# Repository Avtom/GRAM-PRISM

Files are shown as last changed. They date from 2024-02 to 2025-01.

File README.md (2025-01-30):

# GRAM PRI$M

# Introduction 
The **PRI$M** is a modular take on the Prism, originally designed by WunWae. It has the standard pinout for firmwares like HayBox and Pico-Rectangle, and is also compatible with more fleshed-out FGC firmwares like GP2040-CE. The key distinctive features between the original Prism and the PRI$M is the USB-C connectivity, and the modular panels that can be replaced and swapped to change the hand layouts without purchasing a whole new controller. With industrial design from GRAM, PCB designed by Quark.Works, this guide goes over a DIY-friendly approach to building and modifying the PRI$M to suit your needs.

**If you would like to support the developers of this project, consider purchasing parts like buttons, PCBs, USB-C to GCC cables, and official GRAM builds at [GRAMCTRL.COM](https://www.gramctrl.com) rather than a fab house.**

For the Arcade version of the PRI$M, please go to [this section of the documentation](https://github.com/Avtom/GRAM-PRISM/tree/arcade-V1/Arcade%20%20v1)

IMG_8768 (1)

Included Files
-
Included in this repo is all the files needed to get started with a PRI$M build:
- **PRI$M Frame .stl files**
- **Aluminum Panel** Gerber files *(5 of 'em!)*
- **PCB Gerbers** for multiple hand layouts and a panelized version for the standard layout

Additional Information
-
If you want more info around GRAM builds, both open source and official builds, please join the [GRAM Digital Controllers Discord](https://discord.gg/6TuHw2r2X4) to ask questions and work with the community! I would love to see people creating new interesting designs, and building upon our initial framework.

Thanks & Acknowledgements
-
There are several people who made this project possible, either directly or indirectly.
- [Quark](https://twitter.com/quark_works), who did the PCB design on this and many other GRAM projects.
- [WunWae](https://twitter.com/WuhnWae), who developed the ergonomics and original Prism design. Thank you for your blessing on this crazy project!
- My life and business partner [BRUISES](https://twitter.com/bruisesxo), who has turned GRAM into what it is today, and had incredible patience with me as I toiled away at my computer late into the night designing this thing.

# Ordering & Customization Guide
While most of these files are universal and can be used at any fab house, **JLCPCB** has become the de-facto standard for DIY box manufacturing. This is due to their hyper-affordable pricing and low minimum order quantity.

Bill of Materials
-
Per GRAM PRI$M, you will need (some files can be made using this repository, but I will link to places to purchase them if you would like to avoid MOQs)
- 1 x PRI$M PCB set *(either panelized, or individual PCBs)*
- 1 x set of PRI$M Aluminum Panels
- 20 x [Kailh Choc V1 switches](https://www.moergo.com/products/kailh-choc-v1-key-switches-red-brown-white-pro-red-20-pack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) (Red, Red Pro, and Whites are all great choices)
- 20 x [PG1350 Hotswap Sockets](https://mkultra.click/kailh-hotswap-sockets)
- 20 x Choc v1 keycaps *(I recommend MBK profile)*
- 1 x GRAM PRI$M Frame
- 8 x [M5x0.8 8mm Low-Profile Socket Head Screws](https://www.mcmaster.com/92855A507)
- 2 x [M2.5x0.45 4mm Button Head Screws](https://www.mcmaster.com/catalog/130/3434/97763A412)
- 1 x [4" JST 6-pin Socket to Socket Reversed cable assembly](https://www.digikey.com/en/products/detail/jst-sales-america-inc/A06SR06SR30K102A/9922193)
- 1 x [4" 14-pin FPC Cable](https://www.digikey.com/en/products/detail/molex/0152670295/4427171)

*Optional*
- USB-C to GCC cable for console/adapter play

Tools Needed
-
This guide assumes a level of knowledge on soldering and computer literacy. General tool requirements are:
- Soldering iron
- Solder
- USB-C to USB-A cable
- 3mm hex key/allen wrench
- Pliers
- Patience :)

The PCB
-
***Note: Since the ordering process of the PRI$M is almost identical to the [SLIM](https://github.com/GrammyMoney/GRAM-SLIM), I have used the ordering guide from the SLIM here. You may need to do more repetitions of these steps depending on which PCB you are printing, and you need to do the panel steps for all 5 aluminum panels.***

The PCB Fabrication files should come in the form of a *Gerber ZIP file* and *bom/cpl files* (usually in Excel spreadsheet formats).

Drag them into the "Upload Gerbers" box at JLCPCB and this page will pop up:



Here you can change the color of the PCB. Green is the fastest and cheapest from JLC, but their black PCBs look *siiiiiick*. The only setting I recommend you change is to check "**Yes**" on *Confirm Production file*. This allows for any mistakes to be ironed out by their engineers.

Towards the bottom of the page, you want to turn on the switch for **PCB ASSEMBLY**.



Make sure you are assembling the *Bottom Side* of the PCB, and make sure to set *Confirm Parts Placement* to "**Yes**". None of the advanced options need to be changed.

Upon confirming your PCB Assembly options, you'll be taken to the Assembly wizard. Clicking next will give you a location to upload the *BOM* and *CPL* files (*CPL* is referred to as *Positions* in the GRAM Slim files). Once you click through, you'll be brought to you BOM list.



This will allow you to modify parts if there's any low stock. There's a line at the bottom for CH1-CH21 with some red text. This is for assembling hotswap sockets, which is not recommended for JLC, as you have to preorder them. when you click **next**, continue by clicking *Do not place*.



The wizard looks intimidating, but good news! Since you're confirming part placement, the JLC engineers will fix any errors. Just go ahead and continue.

There you have it! Your PCB is ready to order. As of the time of this writing, a set of 5 assembled boards costs $56.07 before shipping.

The Panels
-
The process of ordering aluminum panels from JLC is similar to the PCB ordering process, but much simpler. Start by dragging the **GRAM Slim Top** Zip file into the JLC upload window. We want an aluminum PCB, 1.6mm. You can choose either white or black coating (white tends to be glossy, black is matte but a fingerprint magnet). 



Under High-spec Options, make sure to remove order number, or else they'll put an ugly serial number on the panel.

Once you save to cart, you'll see this screen:



Here you can add the **GRAM Slim Bottom** Zip file, and it will copy all your settings from the Top panel. Save to cart, and you're ready to check out with your PCBs!

*Note: JLCPCB cannot transact PCB and 3D printing orders together, so place this order, then move on to 3D printing.*

The Frame
-
The frame file is pretty self explanatory. Just go into JLC's 3D printing section, drop the STL file in, and choose your material. I recommend black Resin, but LEDO 6060 is a great, low cost alternative. The only material I recommend against is the textured Nylon options, as the tolerances between the frame and panels are extremely tight, and the texture could interfere with that. make sure the surface finish is set to *sanded*. 

The website will flag some possible errors (Inverted normals, Multi-shells, Possible noise shells) but if you have not modified the .stl file you are good to go. It is also possible that their support contact you about a risk of deformation given the geometry of the workpiece but it is normal and you should reply to the email that you accept the risks.



Need help building your PRI$M? Feel free to join our [Discord](https://discord.gg/gramctrl) for advice from our lovely open source community!

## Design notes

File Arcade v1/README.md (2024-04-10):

# GRAM PRI$M ARCADE VERSION

## Table of Content
- [Introduction](#Introduction)
- [How to build the exact same model](#How-to-build-the-exact-same-model)
- [How to modify it and make it even better](#How-to-modify-it-and-make-it-even-better)
- [Dev log](#Dev-log)

## Introduction

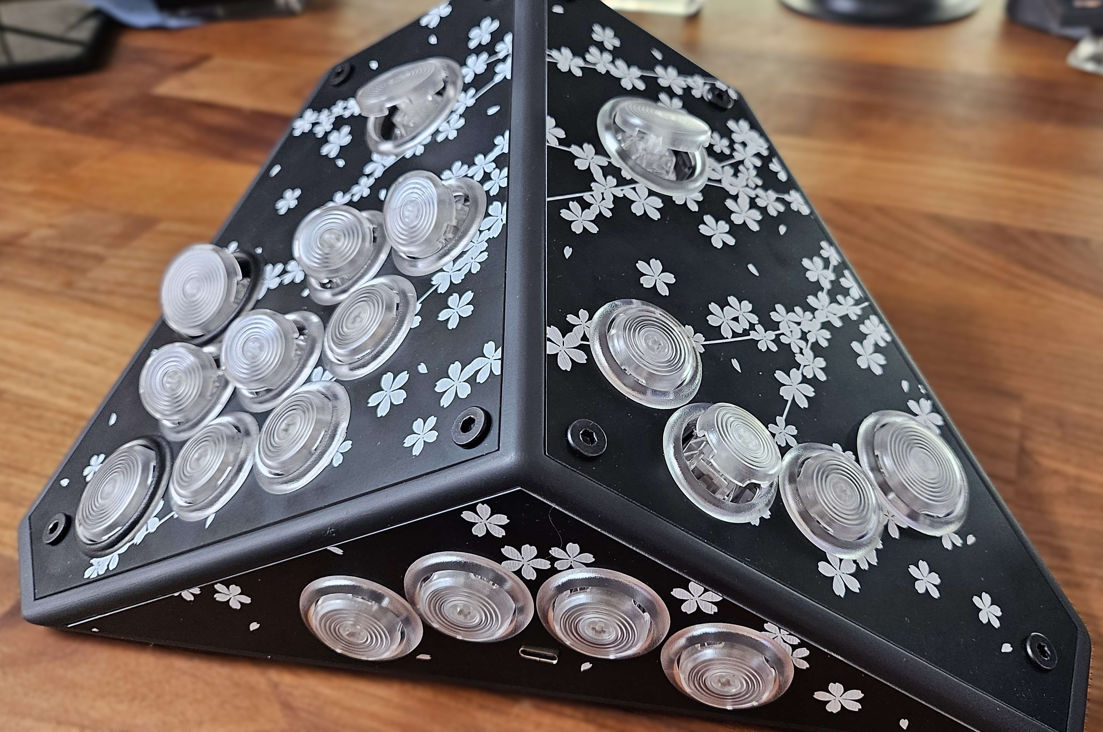
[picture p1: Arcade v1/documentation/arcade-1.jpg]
Arcade


This is an experimental version of the [PRI$M](https://github.com/GrammyMoney/GRAM-PRISM) that fit 24mm and 30mm, relatively low profile, arcade buttons instead of Kaith Choc mini switches.
The goal is to have very fast buttons (short activation point and short bottom out) while keeping your wrist in a comfortable and straight position.
The controller is powered by [RP2040 Advanced Breakout Board](https://github.com/OpenStickCommunity/Hardware/tree/main/RP2040%20Advanced%20Breakout%20Board) running the [GP2040-CE firmware](https://github.com/OpenStickCommunity/GP2040-CE).

## How to build the exact same model

### Bill of materials
- 1 x GRAM PRI$M Frame
    - [stl  here](https://github.com/Avtom/GRAM-PRISM/blob/arcade-V1/Arcade%20%20v1/stl/gram%20prism%20v1%20frame.stl)
    - [instructions here](https://github.com/Avtom/GRAM-PRISM/tree/arcade-V1?tab=readme-ov-file#the-frame)
- 1 x set of Arcade PRI$M Aluminum Panels
    - [look for the .zip files in the exported for JLBPCB folders](https://github.com/Avtom/GRAM-PRISM/tree/arcade-V1/Arcade%20%20v1/kicad)
    - [instructions here](https://github.com/Avtom/GRAM-PRISM/tree/arcade-V1?tab=readme-ov-file#the-panels)
        - Please note that the minimum quantity that you can order is 5 for each panel. Maybe try to find other interested person on discord?
        - Please note that black panels cost significantly more than white one (in case you don’t care about the color)
- 5 x 30mm buttons and 14 x 24mm low profile arcade buttons.
    - The challenge is to find buttons that are not too deep because of the limited space inside the Prism, especially on the side.
        - Punk workshops one are OK, Quanba Gravity KS most likely OK.
	- Sanwa snap-ins and Crowns 202/204 are NOGO.
    - Max diameter of the rim is 29mm for the 24mm buttons and 34mm for the 30mm buttons
- (if you go with snap-in buttons) 1 set of 22-24mm rubber o-rings (likely 2mm thick) and 1 set of 28mm one. 
    - To compensate for the 1.6mm thickness of the panels which is significantly thinner than normal arcade stick enclosure.
- ON/OFF button of 21mm of diameter ([I used this one](https://focusattack.com/mini-round-2-pin-spdt-on-off-rocker-switch-black/))
- Some padding for the bottom panel (foam or rubber). [I went with rubber ones to add more weight to the controller](https://www.amazon.ca/dp/B09KC846TX)
- Wires (typical harness for leverless works well. Depending of the board you will use, you might need extra wires to jst-2pin to connect the ON/OFF and one of the Aux front button. )
- Advanced break board (I used a 5.2 one from [TheTrain](https://github.com/TheTrainGoes)).
- (optional) Adhesive PCB feets to keep the board on the inside of the resin panel. [Example](https://focusattack.com/3mm-hole-low-profile-adhesive-pcb-feet-set-of-4/)
- 8 x low profile M5x0.8 8mm screws.([the ones I used](https://makerparts.ca/products/low-profile-screws-m5?variant=16606601284))
- Usb-c male (90 angle) to female cable (20cm). [Went with a flat ribbon one](https://www.amazon.ca/Degree-Angled-Ribbon-Standard-Charging/dp/B07C4RD344).
- (optional) Mx tilters if you want to adjust the angle of some of the fingers. [I used that](https://3dkeycap.com/products/mx-tilters-adapters-10-pack)     

### Tools
- Solder iron (if you can’t find wires with some connectors on it)
- Super glue or 3M tape for the panels without screws
- Some electrical tape to hold the usb-c femal in place. (not super clean, there is way of doing better than that)

### Assembly
1. Connect the usb-c cable and harness to the board.
2. Stick the board inside of the frame on the back panel (the only one that is part of the frame) to avoid having the board touching the metal panels (for static eletricity)
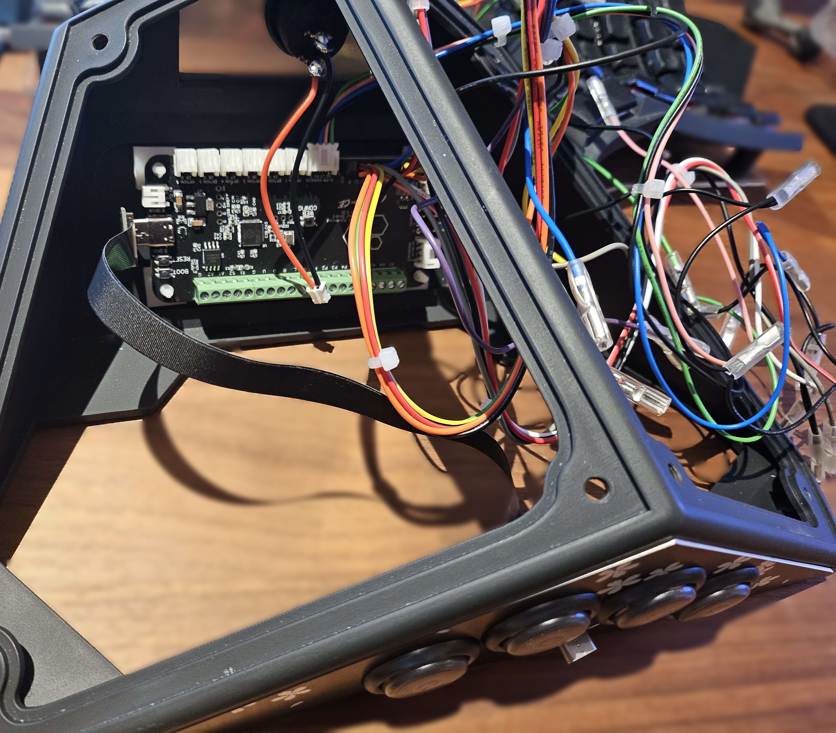
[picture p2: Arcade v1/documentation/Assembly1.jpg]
assembly 1 Assembly 1
    - 
3. Get the back panel ready:
    1. Install/solder the cables on the button
    2. Put the button in place
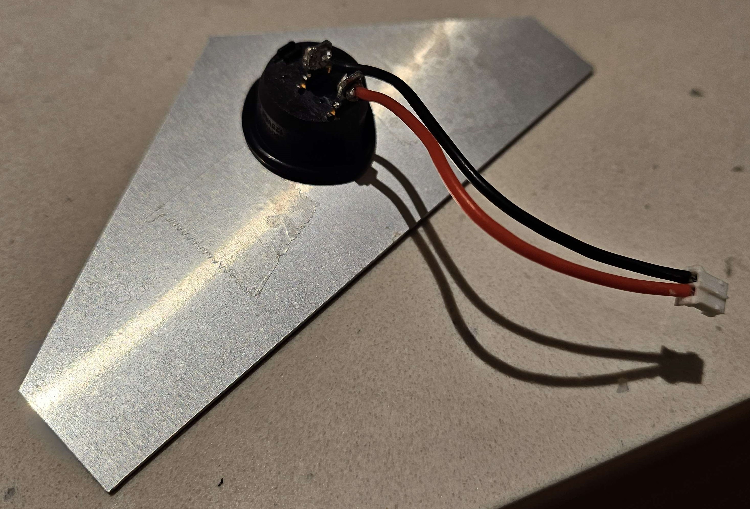
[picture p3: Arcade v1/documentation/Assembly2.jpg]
assembly 2 Assembly 2
	- 
    3. Connect the cable to the board
4. Get the usb female in place
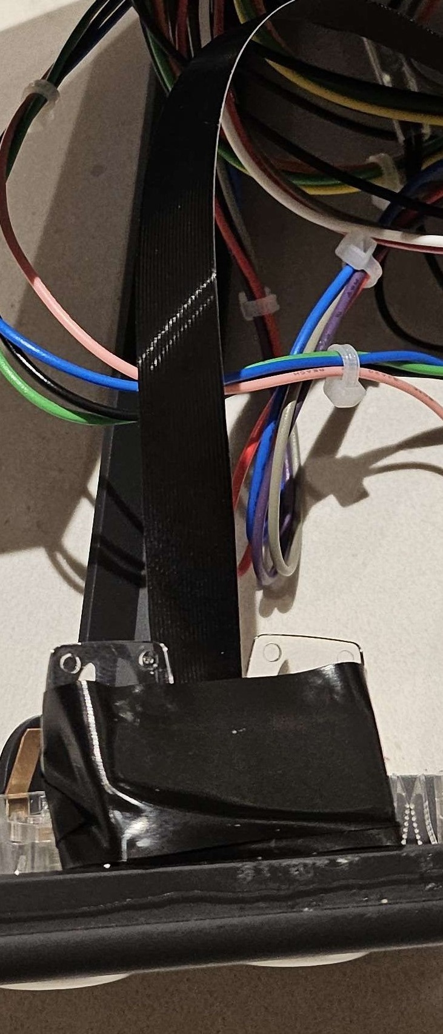
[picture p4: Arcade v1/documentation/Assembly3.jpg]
assembly 3 Assembly 3
    - 
5. Get the front pannel ready:
    1. Put the button in place and glue the board
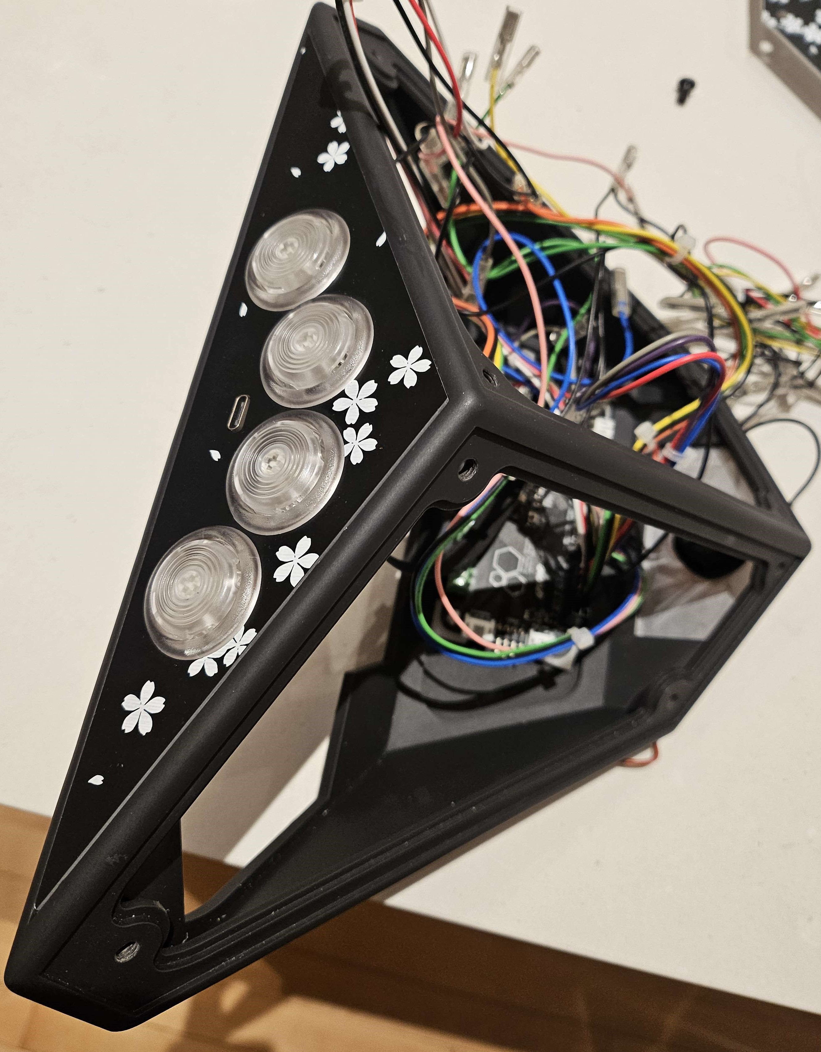
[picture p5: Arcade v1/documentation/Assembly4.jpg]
assembly 4 Assembly 4
       - 
6. Get the bottom pannel ready:
    1. Cut a rectangle in the foam/rubber if you want the GP2040-CE logo visible
    2. Stick the pad on the bottom panel and cut what remains on the sides after
    3. Glue the panel to the frame.
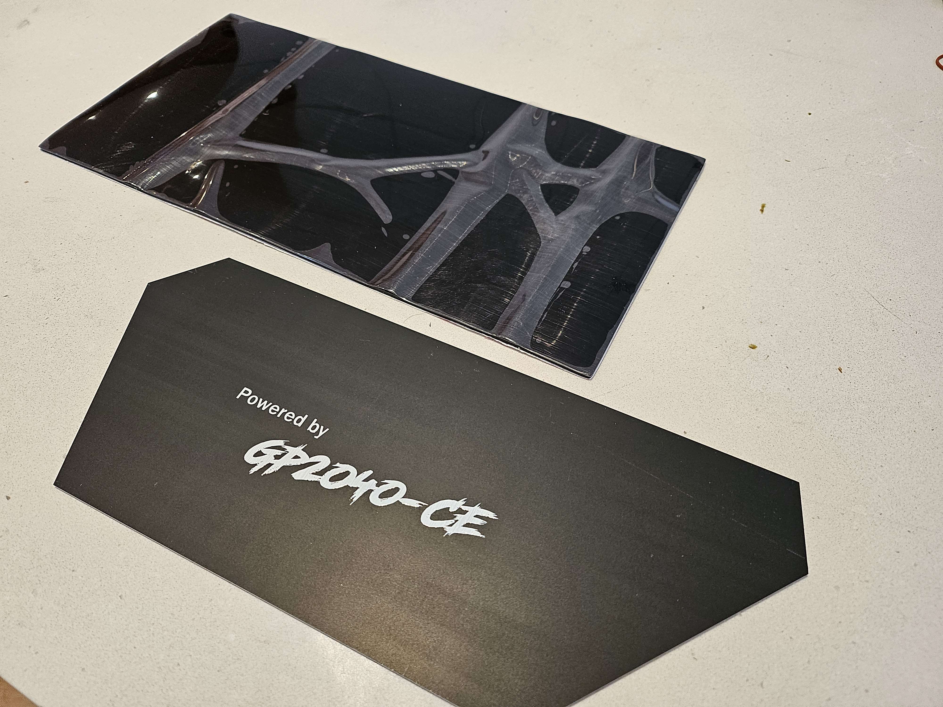
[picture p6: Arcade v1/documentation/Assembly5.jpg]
assembly 5 Assembly 5
        - 
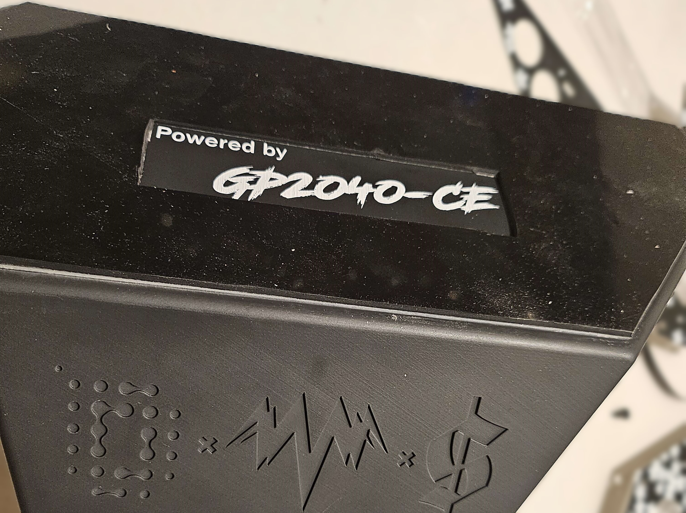
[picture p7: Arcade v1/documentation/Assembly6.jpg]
assembly 6 Assembly 6
        - 
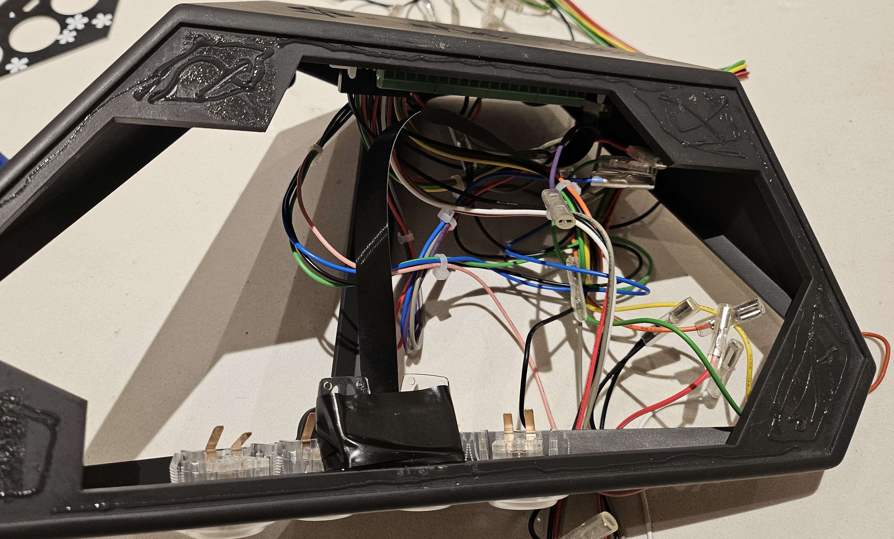
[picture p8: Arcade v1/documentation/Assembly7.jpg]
assembly 7 Assembly 7
        - with the glue in 
7. Get the 2 top pannel ready:
    1. Get the bottons in. Don’t forget the o-rings if you are using snaps-in.
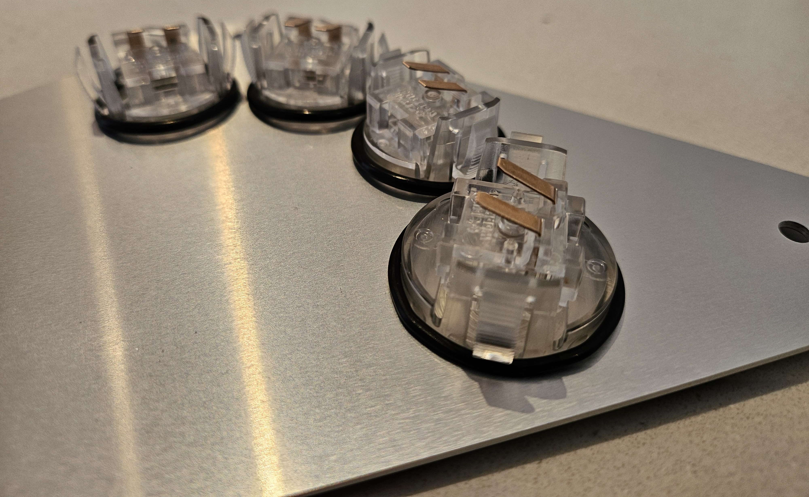
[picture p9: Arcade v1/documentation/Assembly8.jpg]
assembly 8 Assembly 8
        - 
    2. Do the wiring
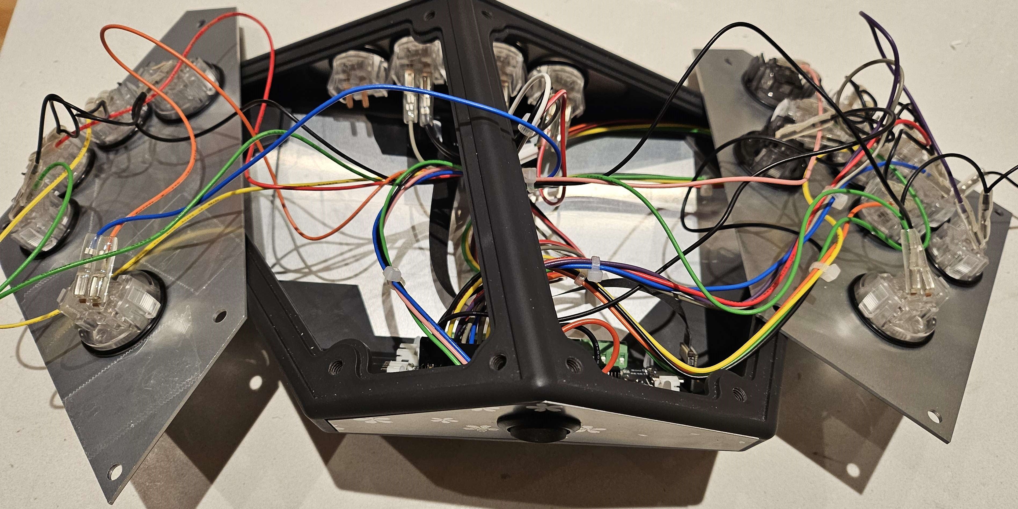
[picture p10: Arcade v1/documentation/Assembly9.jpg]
assembly 9 Assembly 9
        - 

## How to modify it and make it even better

- If you want to iterate on the layout of the buttons, you can use the .ai files.
   - Make sure the buttons are not too close from each others
   - Keep using mm as a unit everywhere
   - Use the helpers to see where the inner layer of the frame stops
   - When done, export to dxf (in illustrator you need to select the shapes who want, then export, then there is a checkbox for exporting only the selected ones)
   - Need dxf can be imported in kicad (as graphics) if you want metal panels, but I recommand 3D printing them first to validate the layout is playable (I used Autodesk fusion to extrude the shape. 2mm thick is ok)

- if you want to change the art, the .psd files is available. But basically you just need to export 5 png (one for each panel) that you will be able to import in Kicad (the art to bitmap convertor).
   - For metal panels, only black and white art works.
   - In photoshop you can make a selection, rotate it, and then copy the content of the selection, that you can open a new file and copy it inside then export.
   - All the masks and the layout overlay are just helpers, you don’t want to export with them on. (in Photoshop: shift-click to activate or desactivate a mask. Alt + drag and drop to duplicate a mask on a different layer)

## What should be improved first?

- The usb-c passthrough situation is the first thing that needs to be dealt with.
   - Dirty solution is to move the usb-c somewhere else and instal a typical passthrough that you can find in most arcade shops
   - The better solution is to take the usb-c breakout pcb from the original [PRI$M](https://github.com/GrammyMoney/GRAM-PRISM) and modify it to be a passthrough instead of one that end with a JST connector.

## Dev log

Here is the different steps taken to create this version of the **PRI$M**:
- Print the stl frame (through JLBPCB)
- Use cardboard to prototype the layout of the different panels
    - Using a circular cutter made that process way easier
    - It was a good opportunity to check that there is enough room under the panels for all the buttons to fit
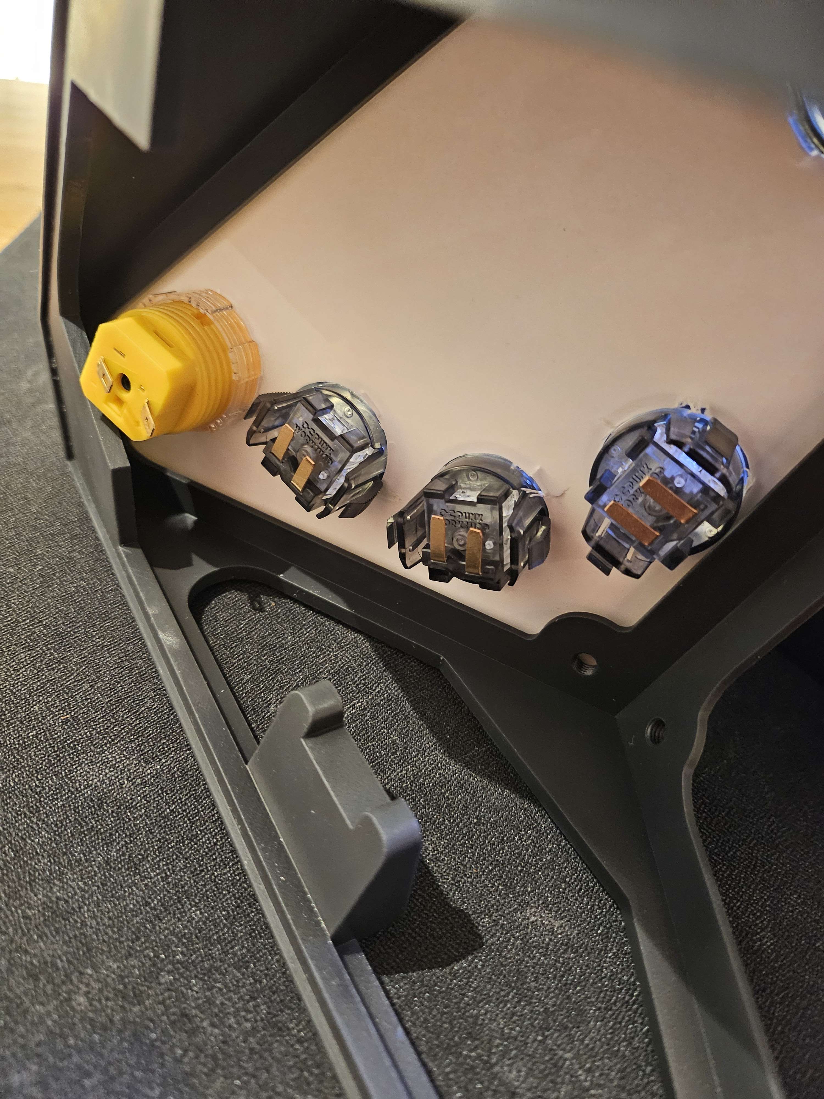
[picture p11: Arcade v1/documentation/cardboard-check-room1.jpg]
cardboard test 1 Card board test 1
        - 
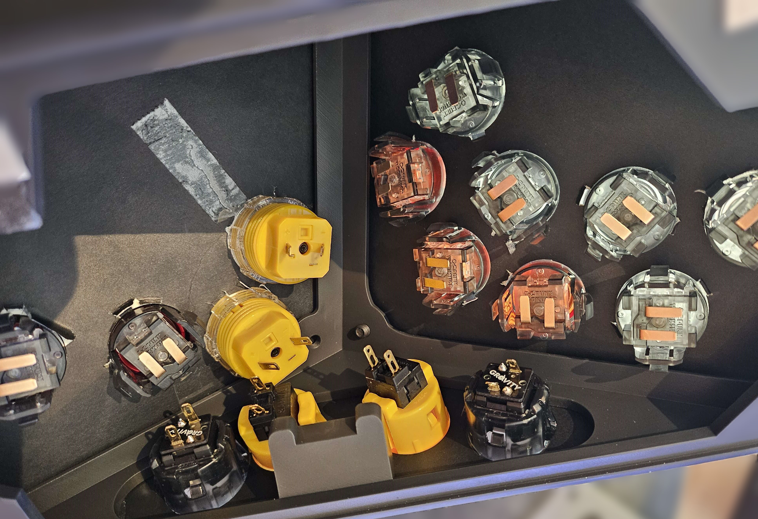
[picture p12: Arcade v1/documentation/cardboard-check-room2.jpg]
cardboard test 2 Card board test 2
        - 
    - Different version of the layout have been born out of this experiment, with different placement and size of the Aux buttons (start, select, etc) and with and without a focus mode button
    - Tip: the correct way of holding the Prism is with the top middle edge perpandicular to you. Meaning the controller will be tilted with your right hand closer to you than your left hand.
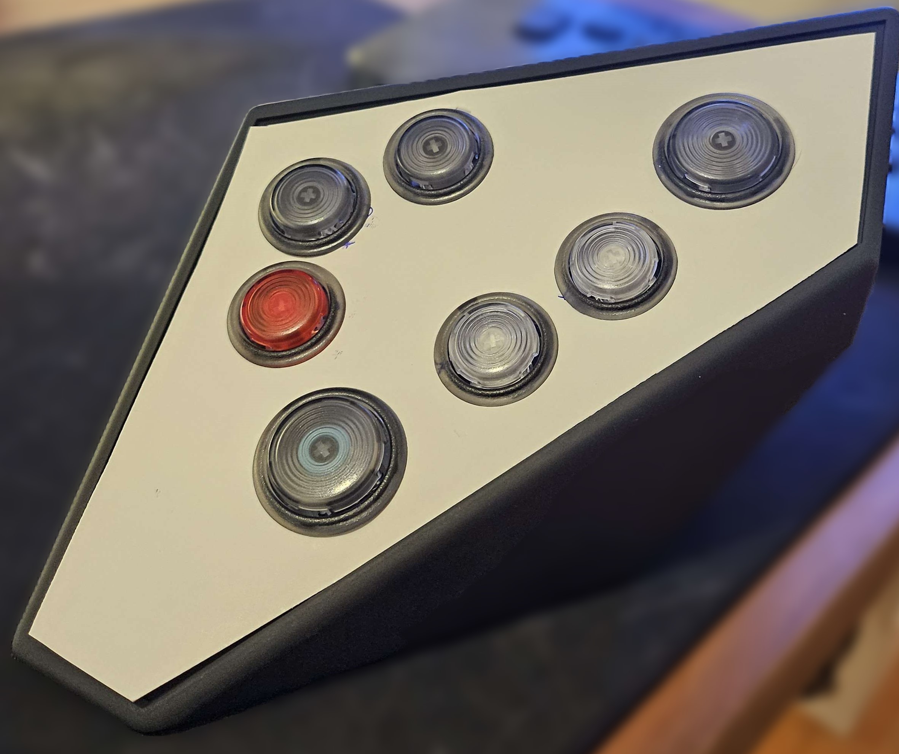
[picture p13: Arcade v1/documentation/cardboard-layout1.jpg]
cardboard layout 1 Card layout test 1
    - 
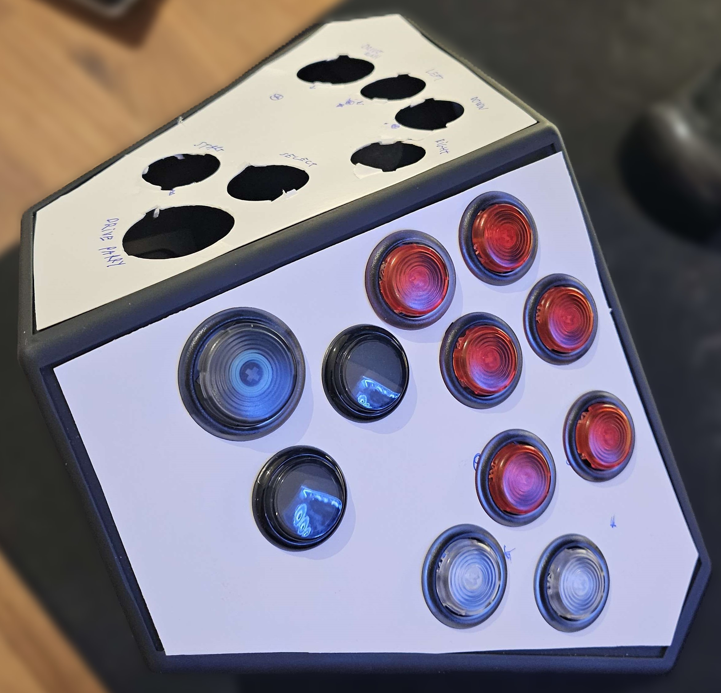
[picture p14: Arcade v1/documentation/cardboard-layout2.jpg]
cardboard layout 2 Card layout test 2
    - 
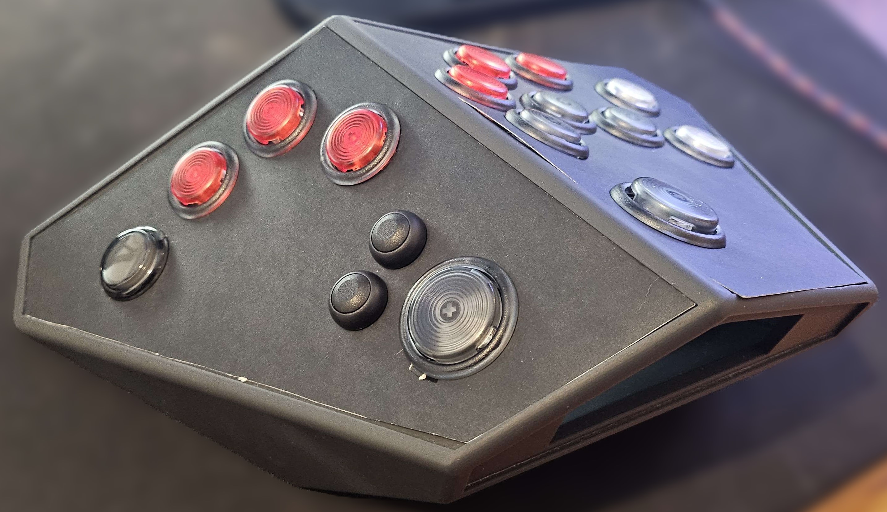
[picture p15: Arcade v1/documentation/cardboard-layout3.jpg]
cardboard layout 3 Card layout test 3
    - 
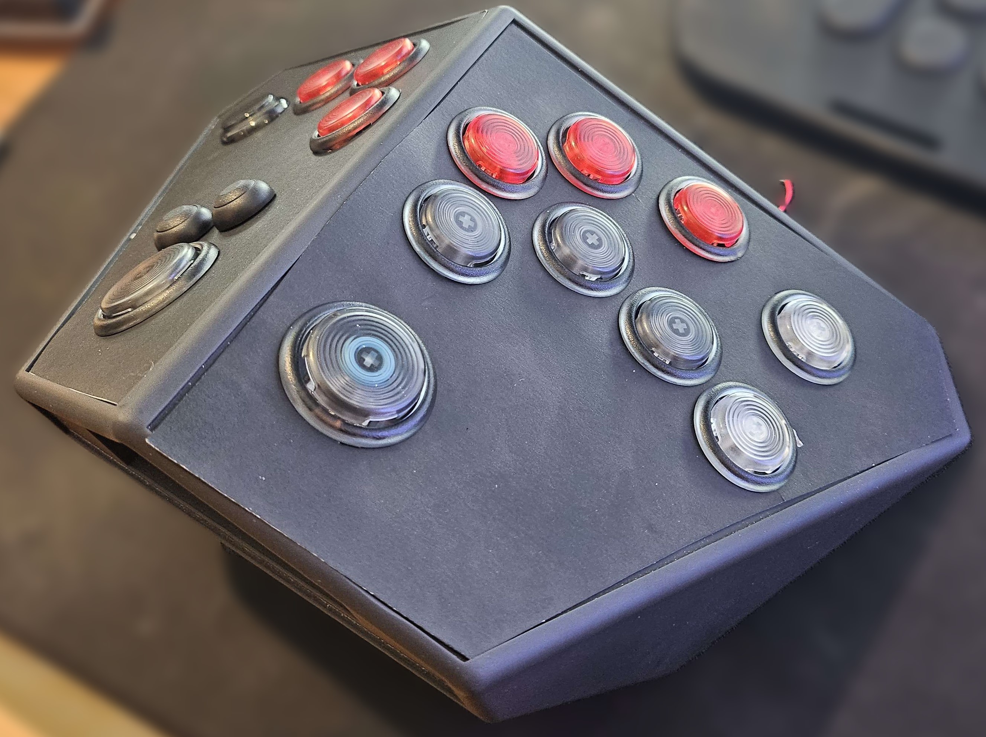
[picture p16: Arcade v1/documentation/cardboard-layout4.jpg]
cardboard layout 4 Card layout test 4
    - 
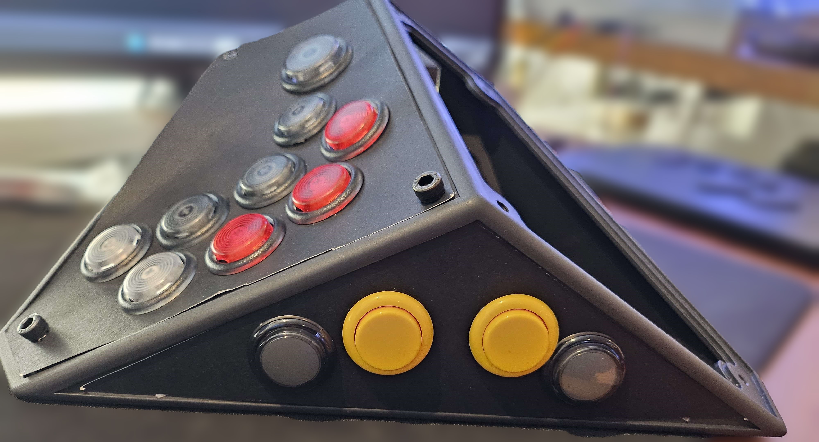
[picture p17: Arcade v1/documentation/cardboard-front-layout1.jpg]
cardboard front layout Card front layout
    - 
- Import the dxf of the GRAM PRI$M V1 in illustrator and replicate the layout prototyped with the cardboard
    - [Ai files](https://github.com/Avtom/GRAM-PRISM/tree/arcade-V1/Arcade%20%20v1/illustrator)
- Generate a new dxf out of the illustrator files.
    - [Dxf files](https://github.com/Avtom/GRAM-PRISM/tree/arcade-V1/Arcade%20%20v1/dxf)
- Import the dxf in Autodesk Fusion and extrude the surface to create an stl file.
    - stl files are not mandatory, but it was used to 3D print the panels in order to find out possible mistake made in the creation process so far (and one issue was found with the wrong unit being used). 
        - [Stl files](https://github.com/Avtom/GRAM-PRISM/tree/arcade-V1/Arcade%20%20v1/stl/stl%202mm%20thick)
- Checking the layout with a cardboard has it’s limits. It was nice to figure out if how buttons fits in the frame and how to place them under fingers but the lack of rigidity prevented in game testing while playing at full speed. This is where the 3D prints became handy and revealed flaws of the early cardboards layouts (things getting tiring after 30 min of playing tense matches, etc)
    - Lots of iterations were printed to until a good, playable, layout was found.
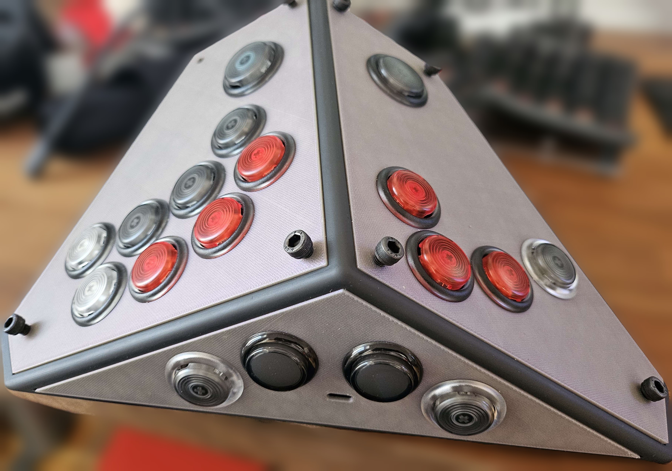
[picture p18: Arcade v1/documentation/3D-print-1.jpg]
3D print layout 1
      - 
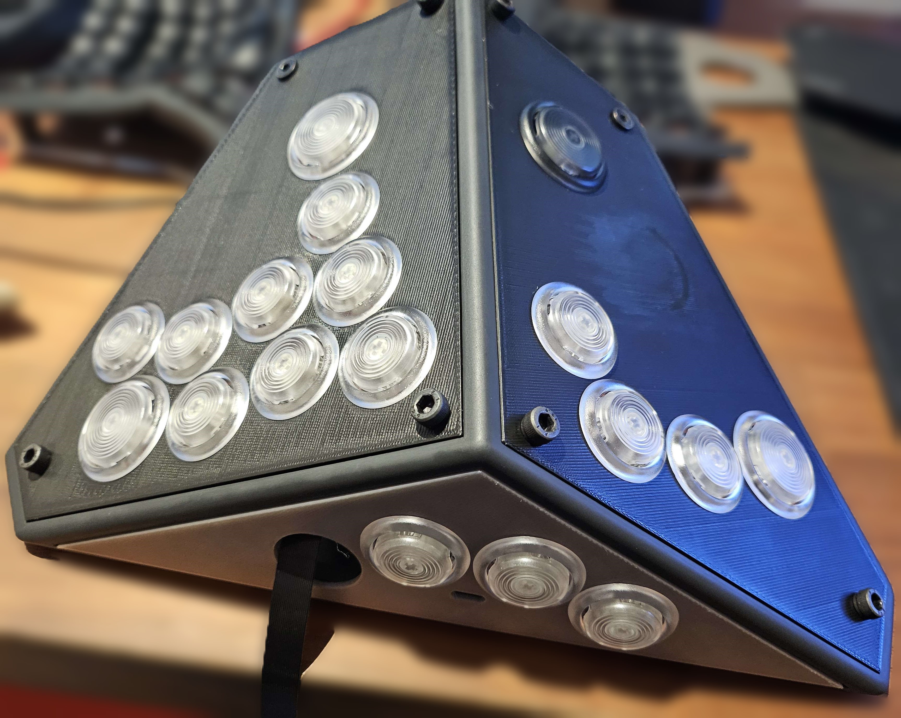
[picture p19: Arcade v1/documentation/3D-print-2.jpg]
3D print layout 2
      - 
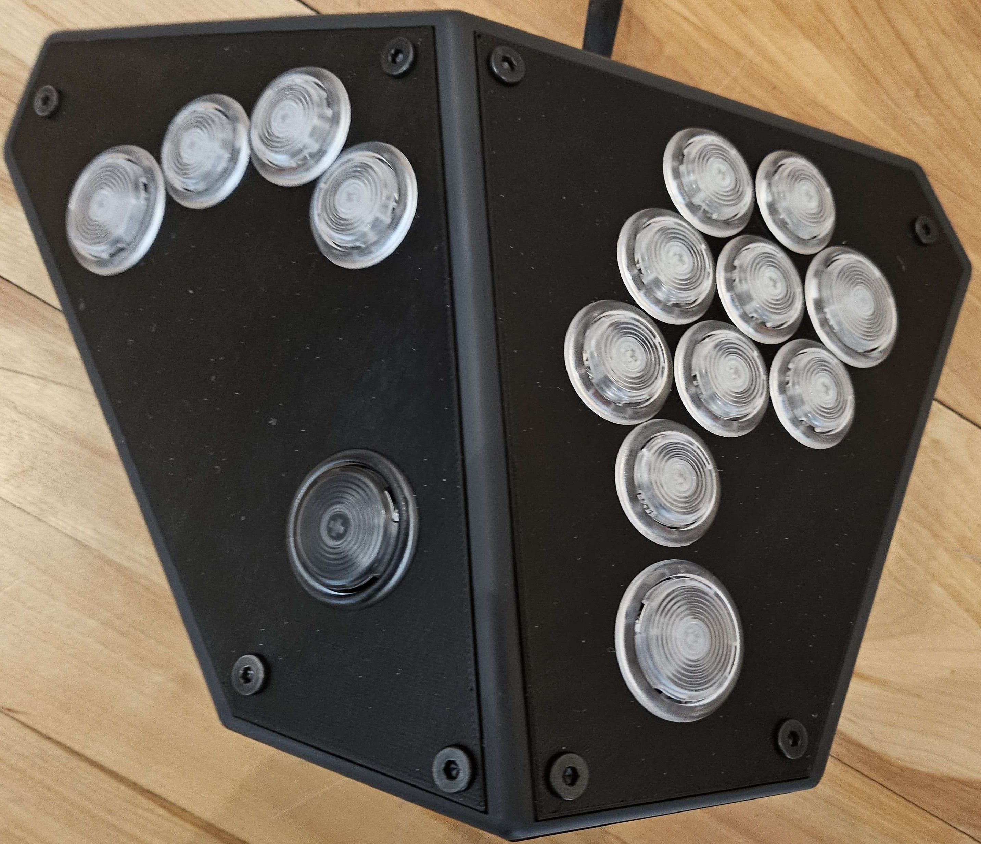
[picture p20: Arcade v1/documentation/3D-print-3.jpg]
3D print layout 3
      - 
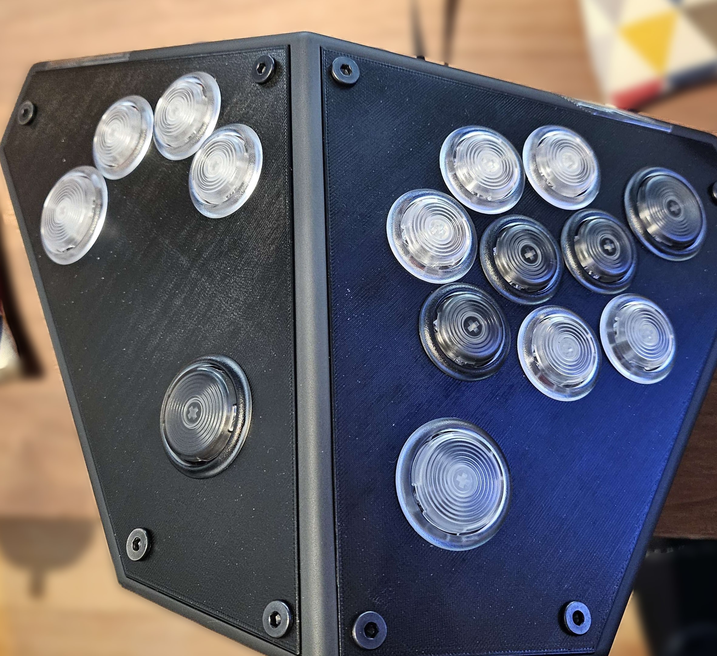
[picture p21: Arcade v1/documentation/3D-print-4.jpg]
3D print layout 4
      - 
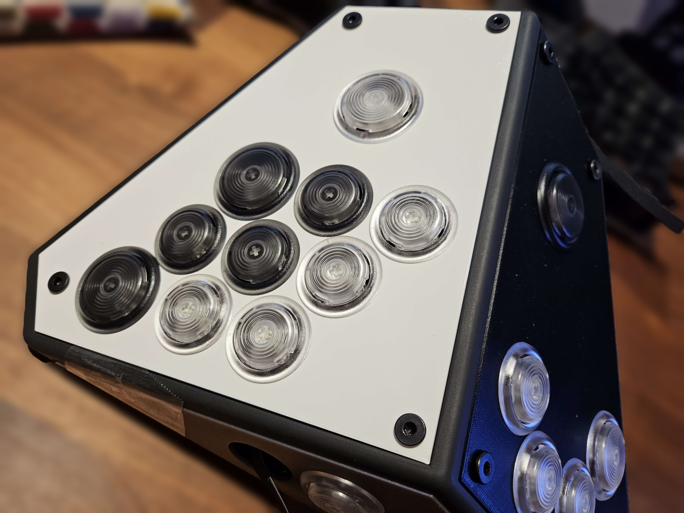
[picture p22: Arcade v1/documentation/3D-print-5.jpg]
3D print layout 5
      - 
      - prototype layout 1
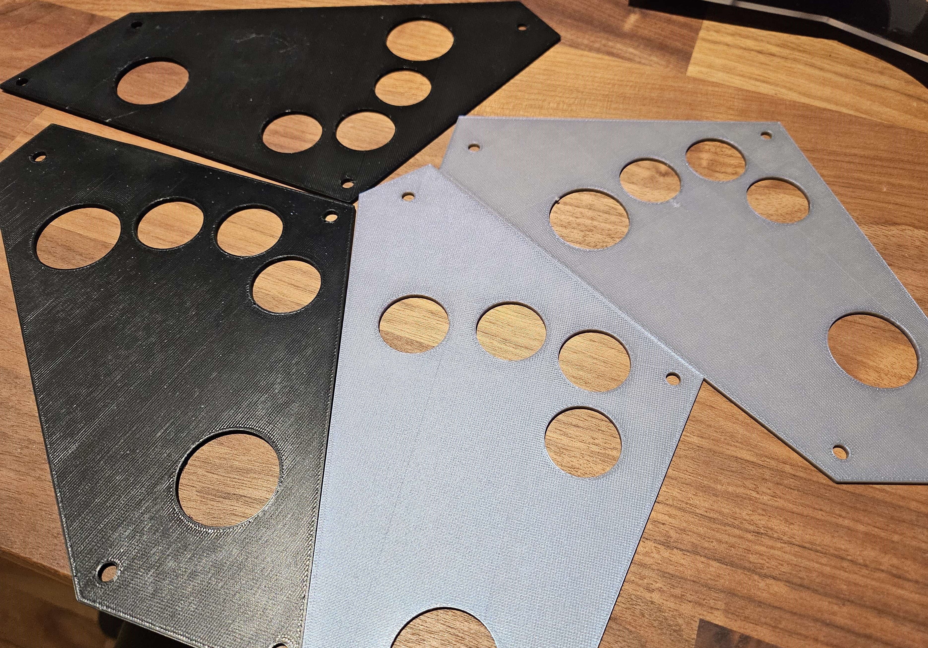
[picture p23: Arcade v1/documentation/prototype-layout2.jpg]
prototype layout 2
      - 
- The art for panels has been designed in Photoshop and the exported in png
    - [Photoshop files](https://github.com/Avtom/GRAM-PRISM/tree/arcade-V1/Arcade%20%20v1/art)
- Once the layout were locked, then the last step was designing the panels in KiCad (as we are basically manufacturing aluminium pcb to make metal panels).
    - Import the dxfs as graphics for the edge.cuts layer
    - Import the art in the bitmap tool of Kicad and then copy/paste it as a silkscreen layer.
    - Plot everything to export the gerber files
- Ran into problem with the hand screws I had that happened to be be to tall and in the way when holding the controller.
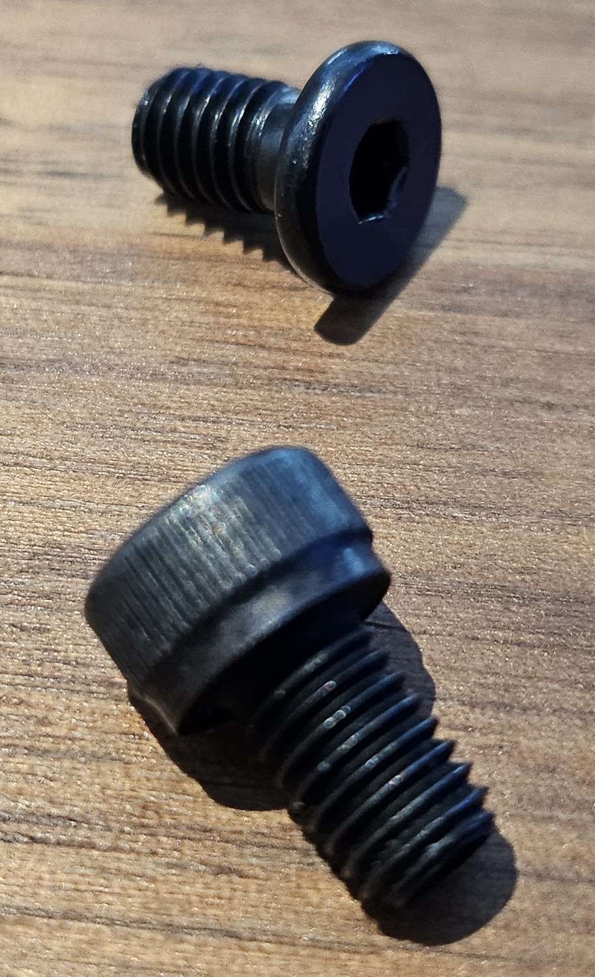
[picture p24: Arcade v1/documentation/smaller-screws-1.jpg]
Smaller Screws 1 Smaller screws 1
    - 
    - Smaller Screws 2 Smaller screws 2
- Order the pcbs (through JLBPCB again)
   - Metals panels Metal Panels
- Assemble the beast.
    - With some improvisation on the usb-c passthrough part… initial plan didn’t worked out so some spare plastic part have been glued and the cable tapped to stay in place
    - Outside of the top panels that are screwed, all the others are glued with some super glue.
    - First steps of the assembly:
        - Without Buttons 1 without button 1
	- Whitout Buttons 2 without button 2

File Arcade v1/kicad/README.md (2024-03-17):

Gerber files (usually used for PCB designs) can be used to create 1.6mm aluminium panels with some nice art on it.
KiCad (free software) is used to author the PCBs.
The idea is to import the dxf as graphics and make it a edge.cuts layout.
png files can be transformed into F.Silkscreen layer within Kicad image converter.
Final step is to export (aka Plot) everything and zip it (https://www.youtube.com/watch?v=ENmDnoKs2hM)

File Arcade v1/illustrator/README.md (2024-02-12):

There is multiple combination possible of panels depending of of where you want the Aux buttons (Start/Select, etc…).
- Either on the front panel
- or on the left side of the left panel with small (8mm diameter) buttons
- or 2x16mm on each top panel

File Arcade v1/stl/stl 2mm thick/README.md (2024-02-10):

Theses .stl have been used to test the models with a 3D printer. They are 2mm thick as it was the minumum tollerance for the printer.

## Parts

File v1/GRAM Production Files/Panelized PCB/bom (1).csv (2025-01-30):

Designator | Footprint | Quantity | Value | LCSC Part #
C1 | 0402 | 1 | 10uF | C15525
C10, C11, C12, C15, C3, C4, C5, C6, C8, C9 | 0402 | 10 | 100nF | C1525
C13, C14 | 0402 | 2 | 22pF | C1555
C16, C17, C2, C7 | 0402 | 4 | 1uF | C52923
C18 | 0603 | 1 | 4.7u | C19666
CH1, CH10, CH11, CH12, CH13, CH14, CH15, CH16, CH17, CH18, CH19, CH2, CH20, CH3, CH4, CH5, CH6, CH7, CH8, CH9 | Kailh_socket_PG1350 | 20 | choc_SW_HS | C5333465
D1 | D_SOD-123 | 1 | Schottky Diode | C8598
D2 | 0805 | 1 | GREEN | C2297
D3 | D_SOD-323 | 1 | Schottky Diode | C191023
F1 | 1206 | 1 | 500 mA | C151162
J2, J5 | TE_1-84953-4_1x14-1MP_P1.0mm_Horizontal | 2 | FFC Connector | C262348
J3, J8 | JST_SH_SM06B-SRSS-TB_1x06-1MP_P1.00mm_Horizontal | 2 | JST Connector | C160405
J6 | TYPE-C_24P_QCHT | 1 | USB C Connector | C456013
R1, R2 | 0603 | 2 | 27 | C25190
R10, R11 | 0603 | 2 | 5.1k | C23186
R3, R8 | 0402 | 2 | 10k | C25744
R4, R5 | 0402 | 2 | 1k | C11702
R6 | 0603 | 1 | 5.6k | C23189
R7 | 0603 | 1 | 10k | C25804
R9 | 0603 | 1 | 1M | C22935
SW1 | SW_SPST_SKQG_WithStem | 1 | Boot | C318884
U1 | RP2040-QFN-56 | 1 | RP2040 | C2040
U2 | SOIC-8_5.23x5.23mm_P1.27mm | 1 | W25Q128JVS | C97521
U3 | SOT-23 | 1 | XC6206 | C5446
U4, U5 | SOT-23-6 | 2 | USBLC6-2SC6 | C7519
Y1 | Crystal_SMD_3225-4Pin_3.2x2.5mm | 1 | 12MHz | C9002

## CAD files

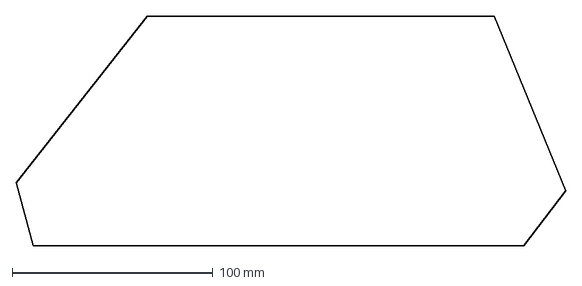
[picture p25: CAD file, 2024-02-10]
Arcade v1/dxf/bottom.dxf
273.9 x 114.6 mm

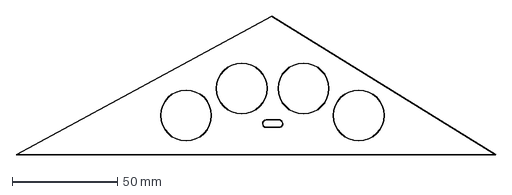
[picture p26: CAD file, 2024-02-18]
Arcade v1/dxf/front with port/front with port and 24mm Aux.dxf
228.1 x 65.9 mm

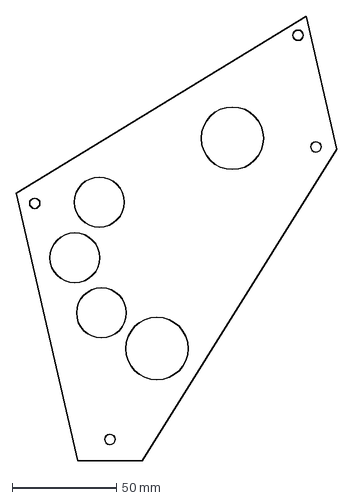
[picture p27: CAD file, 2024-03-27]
Arcade v1/dxf/left panel/left panel no aux buttons.dxf
153.9 x 213.6 mm

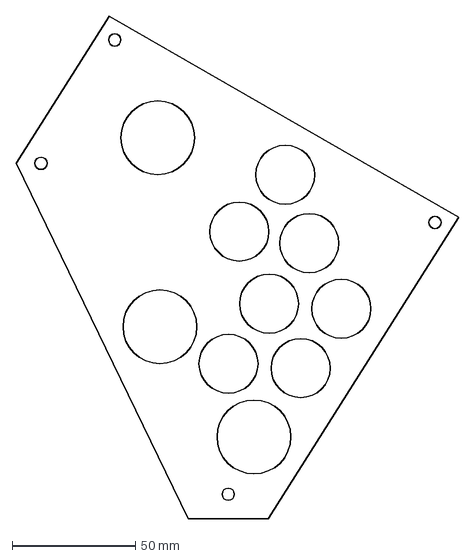
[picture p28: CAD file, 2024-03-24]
Arcade v1/dxf/right panel/right panel no aux buttons.dxf
179.7 x 204.3 mm

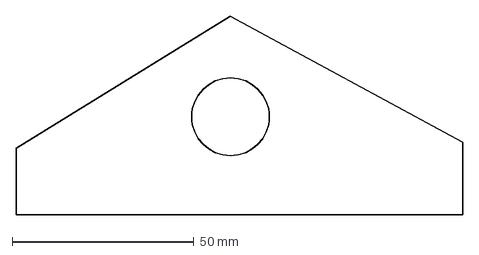
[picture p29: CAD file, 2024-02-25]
Arcade v1/dxf/smallest back/smallest back with focus button.dxf
122.6 x 54.6 mm

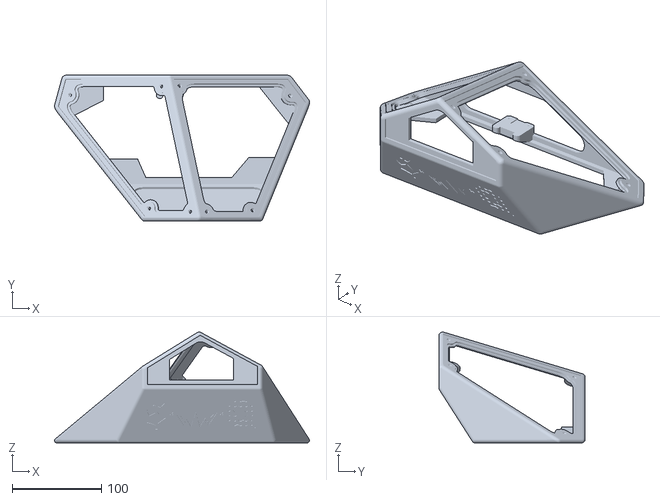
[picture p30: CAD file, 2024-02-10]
Arcade v1/stl/gram prism v1 frame.stl
285.0 x 163.6 x 124.0

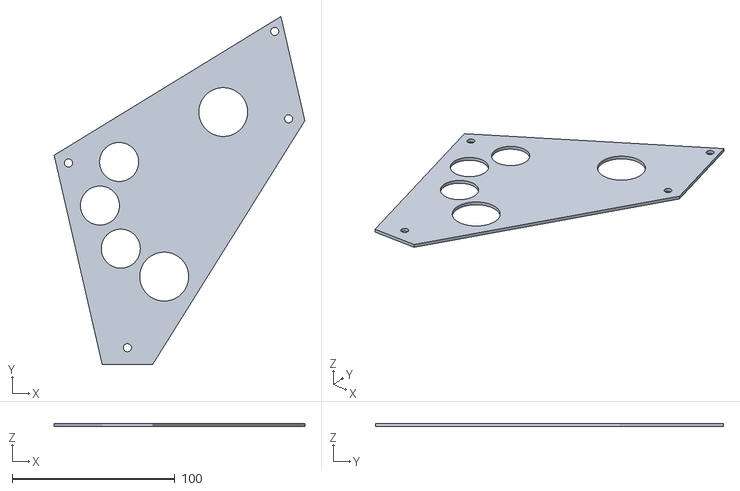
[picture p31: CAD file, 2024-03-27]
Arcade v1/stl/stl 2mm thick/left panel no aux buttons v1.stl
153.9 x 213.6 x 2.00

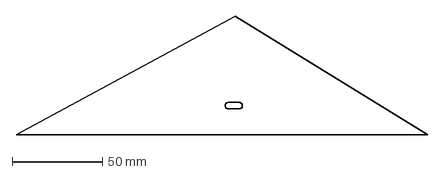
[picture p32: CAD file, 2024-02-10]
Arcade v1/dxf/front with port/front with port.dxf
228.1 x 65.9 mm

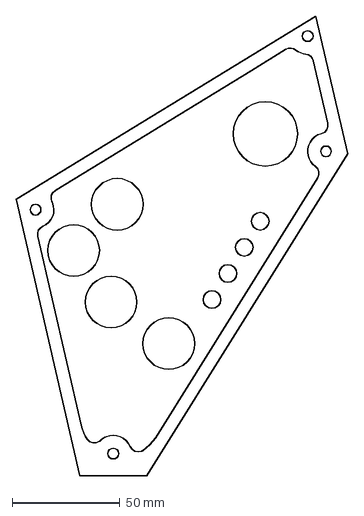
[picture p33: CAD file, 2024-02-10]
Arcade v1/dxf/left panel 8mm aux buttons.dxf
153.9 x 213.6 mm

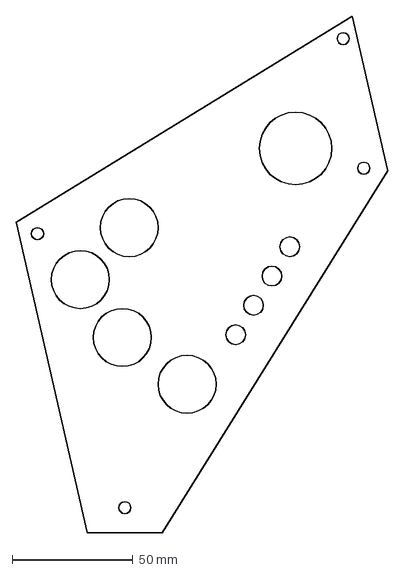
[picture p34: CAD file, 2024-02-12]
Arcade v1/dxf/left panel/left panel 8mm aux buttons.dxf
153.9 x 213.6 mm

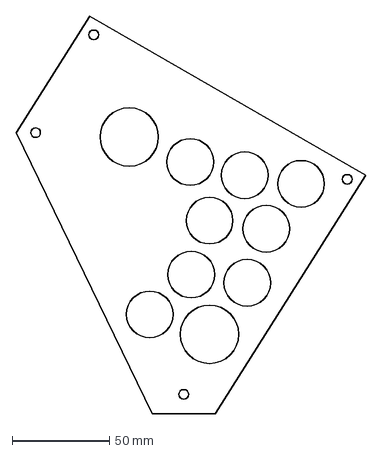
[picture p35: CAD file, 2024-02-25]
Arcade v1/dxf/right panel/right panel no aux buttons alt version.dxf
179.7 x 204.3 mm

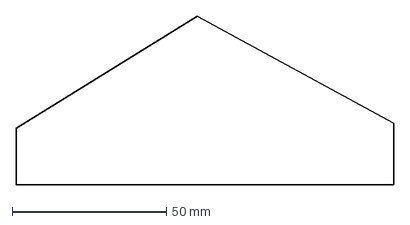
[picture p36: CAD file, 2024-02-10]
Arcade v1/dxf/smallest back/smallest back.dxf
122.6 x 54.6 mm

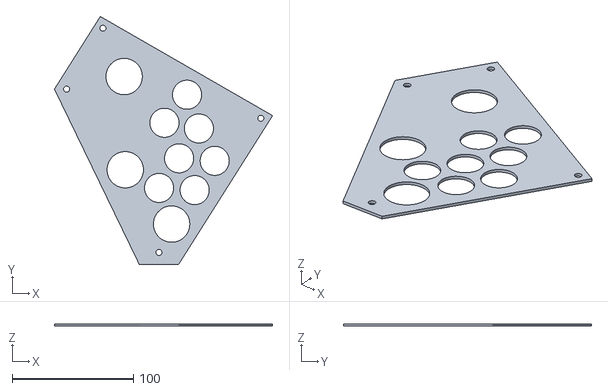
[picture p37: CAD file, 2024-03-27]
Arcade v1/stl/stl 2mm thick/right panel no aux buttons v1.stl
179.7 x 204.3 x 2.00

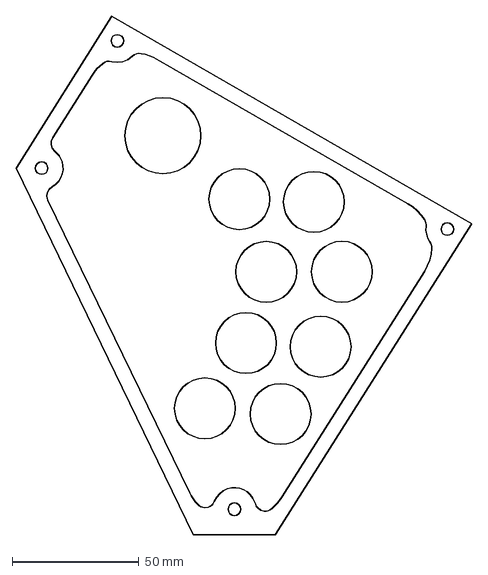
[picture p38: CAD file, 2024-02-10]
Arcade v1/dxf/right panel 8mm aux buttons.dxf
179.7 x 204.3 mm

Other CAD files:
Arcade v1/stl/stl 2mm thick/right panel no aux buttons alt version v1.stl
Arcade v1/dxf/left panel 16mm aux buttons.dxf
Arcade v1/stl/stl 2mm thick/bottom v1.stl
Arcade v1/dxf/right panel 16mm aux buttons.dxf
Arcade v1/stl/stl 2mm thick/front with port and 24mm Aux v1.stl
Arcade v1/stl/stl 2mm thick/smallest back with focus button v1.stl

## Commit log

2024-02-10 [Arcade] Add a first, untested version of the panels
    [gram prism v1 frame.stl, left panel 16mm aux buttons v1.stl, right panel 16mm aux buttons v1.stl]
2024-02-10 [Arcade] Adding dxf files for the 2 top panels
    [left panel 16mm aux buttons.dxf, right panel 16mm aux buttons.dxf]
2024-02-10 [Arcade] Add top panels with 8mm aux button on the left side instead of 2x16mm on both side
    [left panel 8mm aux buttons.dxf, right panel 8mm aux buttons.dxf]
2024-02-10 Add front/back/bottom ai and dxf
    [bottom.dxf, front with port.dxf, smallest back with focus button.dxf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]
2024-02-12 [Arcade] clean + no aux right-left panels + 4 aux front panel
    [front with port and 24mm Aux v1.stl, front with port and 24mm Aux.dxf, front with port.dxf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]
2024-02-12 [Arcade] Small cleanup of the alignment of the buttons for the front panel
    [front with port and 24mm Aux v1.stl, front with port and 24mm Aux.dxf]
2024-02-17 [Arcade] Update the left panel
    - After playtesting with a 3D printed version, making some small adjustments to the button layout.
    - Swapping the pinky button for a 30mm one (as it is a reaction button and there is enough room for it)
    - Adding some approximation of the inner rim and the out frame in the .ai files
    [left panel no aux buttons v1.stl, left panel no aux buttons.dxf]
2024-02-18 [Arcade] update the right panel
    After more playtesting with a 3D printed model.
    - Moving the thumb closer to the second row
    - Moving the second row to the left
    [right panel no aux buttons v1.stl, right panel no aux buttons.dxf]
2024-02-18 [Arcade] Front panel
    Rework the front panel to be able to accommodate 4 punk workshop 24mm button
    [front with port and 24mm Aux v1.stl, front with port and 24mm Aux.dxf, smallest back with focus button v1.stl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]
2024-02-24 [Arcade] new iteration of the left panel
    More iteration on the left panel after 3D printing the previous iteration.
    - Keeping the 30mm button under the pinky.
    - slightly moving the ring and pinky button higher on the frame
    [left panel no aux buttons v1.stl, left panel no aux buttons.dxf]
2024-02-25 [Arcade] increase the size of the hole in the back panel after 3D print test
    [smallest back with focus button v1.stl, smallest back with focus button.dxf]
2024-02-25 [Arcade] left panel
    - move all the buttons slightly to the left as a comfort test
    [left panel no aux buttons v2.stl, left panel no aux buttons.dxf]
2024-02-25 [Arcade] add an .stl file for the bottom panel
    [bottom v1.stl]
2024-02-25 [Arcade] Add a new version of the right panel with a different layout
    Explore the idea of having one more button on the lright panel for the pinky and move L3 and R3 accordingly
    [right panel no aux buttons alt version v1.stl, right panel no aux buttons alt version.dxf]
2024-02-26 [Arcade] submitted wrong stl
    [left panel no aux buttons v1.stl, left panel no aux buttons v2.stl]
2024-03-14 [Arcade] Latest iteration of left and right panel
    [left panel no aux buttons v1.stl, left panel no aux buttons.dxf, right panel no aux buttons v1.stl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]
2024-03-15 [Arcade] new iteration of the left and right panels
    left: move the pinky a bit closer
    right: move the top row to be a bottom row instead
    [left panel no aux buttons v1.stl, left panel no aux buttons.dxf, right panel no aux buttons v1.stl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]
2024-03-16 [Arcade] V1 of the art
    [left panel no aux.kicad_sch]
2024-03-17 [Arcade] Add art + kicad + zip for the bottom panel
    [Bottom pannel-B_Cu.gbl, Bottom pannel-B_Mask.gbs, Bottom pannel-B_Paste.gbp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]
2024-03-17 [Arcade] Add the gerber files and kicad project for the back panel
    [back panel-B_Cu.gbl, back panel-B_Mask.gbs, back panel-B_Paste.gbp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]
2024-03-17 [Arcade] fix typo in folder name
    [Bottom pannel-B_Cu.gbl, Bottom pannel-B_Mask.gbs, Bottom pannel-B_Paste.gbp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]
2024-03-17 [Arcade] gerber + kicad for the front panel
    [front panel-B_Cu.gbl, front panel-B_Mask.gbs, front panel-B_Paste.gbp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]
2024-03-23 [Arcade] Final version of the left panel
    [left panel no aux buttons.dxf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]
2024-03-24 [Arcade] Final layout for the right panel
    [left panel 8mm aux buttons.dxf, right panel no aux buttons alt version.dxf, right panel no aux buttons v1.stl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]
2024-03-27 [Arcade] Last minute fix for the left panel
    move the pinky button slightly so it’s not too close from the ring finger.
    [left panel no aux buttons.dxf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]
2024-03-27 [Arcade] update stl
    [left panel no aux buttons v1.stl, right panel no aux buttons v1.stl]
2024-04-07 [Arcade] Update the Readme + photo for the documentation
    [back panel-B_Cu.gbl, back panel-B_Mask.gbs, back panel-B_Paste.gbp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]
